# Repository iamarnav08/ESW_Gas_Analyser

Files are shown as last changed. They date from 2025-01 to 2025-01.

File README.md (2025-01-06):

# ESW-Beyond_Infinity
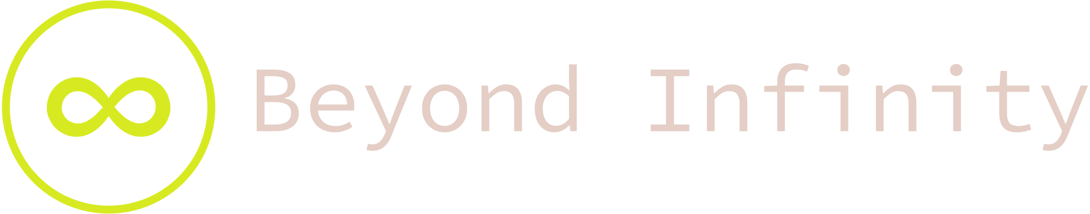
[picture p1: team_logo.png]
team_logo

ESW Project

## Working of MQ 2 sensor

Gases - LPG , CO , smoke

Concentration -> 30 - 500 ppm

Donor atoms (or oxygen vacancies) provide free electrons that can conduct electricity in the tin dioxide.
When the sensor is exposed to air, oxygen gets adsorbed on the surface and traps these donor electrons, reducing conductivity (increasing resistance).
When reducing gases (like methane or CO) are present, they react with the adsorbed oxygen, freeing the donor electrons and increasing the conductivity (lowering resistance).
The sensor measures these changes in resistance (conductivity), and the output voltage increases with the gas concentration because more electrons are available to flow as current.

## Working of MQ7 sensor

The MQ-7 sensor is designed to detect carbon monoxide (CO) using a tin dioxide (SnO₂) sensing element. It works by changing its electrical resistance when CO is present. In clean air, the sensor has high resistance, but when CO interacts with the SnO₂ surface, the resistance decreases.

A key feature of the MQ-7 is its cyclic heating process:

At high temperature (320°C), the sensor cleans itself by adsorbing oxygen molecules.
At low temperature (100°C), the sensor becomes sensitive to CO, reducing its resistance in the presence of CO.
The sensor outputs an analog signal proportional to the CO concentration, making it ideal for CO detectors due to its improved accuracy and selectivity.

## Specialized for CO Detection

MQ-7 is specifically designed to detect carbon monoxide (CO) with high sensitivity. It is fine-tuned through its cyclic heating process, which improves its selectivity for CO and helps reduce interference from other gases. The MQ-7 sensor employs a cyclic heating process, alternating between a high temperature (for cleaning) and a low temperature (for CO detection). This process makes the MQ-7 more selective to CO, reducing false positives from other gases like hydrogen or methane.
The MQ-7 sensor operates on a cyclic heating mechanism with two distinct temperature phases:

High-temperature phase (around 300°C to 350°C): During this phase, the sensor burns off impurities or other gases that may have adsorbed on the surface, ensuring that it is primed for CO detection.
Low-temperature phase (around 100°C to 150°C): This lower temperature is where CO is effectively detected. At this temperature, the CO molecules are adsorbed onto the SnO₂ surface, triggering the redox reaction and thus leading to a measurable change in resistance.

This temperature cycling is essential because it optimizes the sensor's selectivity for CO while minimizing interference from other gases.
Change in Electrical Resistance

## Change in electrical Resistance

As CO is oxidized on the SnO₂ surface, oxygen molecules that were previously adsorbed on the surface as O⁻ ions are released, leading to a reduction in the number of charge carriers trapped on the surface.
This release of oxygen increases the availability of free electrons in the SnO₂ material, leading to a decrease in resistance.
The change in resistance is directly proportional to the concentration of CO in the surrounding air, allowing the sensor to measure CO levels.

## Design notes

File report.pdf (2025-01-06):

# Integrated Gas Analyser

## Course Project for Embedded Systems Workshop EC3.202, Monsoon 2024

Hardik Chadha¹, *, Arnav Sharma², *, Hiten Garg³, *, Kushal Mangla⁴, *, Prof. A. Shrivastava⁵, +
1,2,3,4IIIT Hyderabad,

5CVEST, IIIT Hyderabad
*Team Members,

+Project Advisor

Abstract—Toxic gas exposure in industrial environments, such as manufacturing and chemical processing, poses serious risks to worker safety. Existing gas detection systems are often bulky and lack real-time monitoring, limiting timely responses to hazards; or might be unaffordable for a majority of industrial sites. This project aims to develop a low-cost, portable gas analyzer that enhances safety by providing continuous, real-time detection of harmful gases.

I. INTRODUCTION

Air quality monitoring is becoming increasingly important as environmental pollution, industrial emissions, and household gas leaks pose significant risks to health and safety. Harmful gases like carbon monoxide (CO), smoke, and liquefied petroleum gas (LPG) are major contributors to air pollution and indoor hazards. Real-time monitoring of these gases can help prevent life-threatening incidents by alerting individuals and authorities when the gas concentration reaches dangerous levels.
This paper presents the development of an integrated Gas Analyzer System that detects various harmful gases such as LPG, CO, and smoke using the MQ-2 sensor, and transmits the data wirelessly using LoRaWAN technology. The system is designed to operate in areas with low network coverage and utilizes IoT platforms to provide remote monitoring. This project showcases how embedded systems, sensor technologies, wireless communication, and cloud-based data analysis can be leveraged to create a robust environmental monitoring solution.
The paper details the hardware setup, sensor integration, data transmission via LoRa, cloud data storage using ThingSpeak, CockroachDB and PostgreSQL; and real-time notifications through Twilio, an API service for SMS notifications. We also demonstrate the development of a graphical user interface (GUI) using HTML and CSS to visualize the collected data, making it user-friendly and accessible.

II. PROBLEM STATEMENT

In various industries, toxic gas exposure presents significant health and safety risks to workers. Current solutions often fall short due to their bulkiness, lack of portability and insufficient real-time monitoring, and high costs.
To address these challenges, we aim to develop a low-cost portable gas analyser. The focus will be on making an architecture that can be used to collect and transfer the gas data and is both user-friendly and cost-effective.
The system should be capable of detecting hazardous gases in real-time and transmitting the data wirelessly over long distances. The system must be scalable to monitor multiple locations, offer reliable data visualization, and provide immediate notifications when gas concentrations exceed safety thresholds. Moreover, the solution must work effectively in areas with limited network connectivity, such as rural or industrial zones (mines etc.).
The objective of this project is to design and implement an IoT-based gas monitoring system that integrates gas sensors, long-range wireless communication (LoRaWAN), and cloud-based data storage. The system will offer real-time gas detection, remote monitoring, and automated notifications to ensure timely response to potential hazards, improving overall safety in both industrial and residential environments.

III. OBJECTIVES

Objectives for the project are as follows-
- Real-time Detection of Hazardous Gases: To design a system capable of detecting harmful gases such as LPG, carbon monoxide (CO), and smoke in real-time.
- Long-range Wireless Communication: To implement a reliable, low-power, long-range wireless communication for transmitting gas sensor data over distances of up to few hundred meters.
- Cloud-based Data Storage and Visualization: To enable users to monitor gas concentration levels remotely via a web-based graphical user interface (GUI).
- Automated Threat Notifications: To implement mechanism for sending real-time notifications to users when gas concentrations exceed predefined safety thresholds, ensuring timely response to potential hazards.
- On-site Monitoring: To provide a local monitoring solution using an LCD display that shows current gas levels on-site for immediate assessment.
- Data Redundancy and Offline Access: To ensure data reliability by storing sensor readings locally on an SD card in case of network connectivity loss, allowing periodic retrieval and analysis of historical data.
- User-friendly Web Application: To develop a web-based GUI that allows users to interact with the system, view real-time data, analyze historical gas levels, and configure alerts, making the system accessible and easy to use.
- Scalability for Multiple Locations: To design the system to be scalable and capable of monitoring multiple sites, making it suitable for industrial, residential, and remote environments.

IV. PROPOSED SOLUTION

Our solution comprises of the following components-
- MQ-2 Gas Sensor for Gas Detection: The system uses the MQ-2 gas sensor to detect the concentration of harmful gases such as LPG, CO, and smoke. The MQ-2 sensor provides reasonably accurate measurements of gas concentrations, suitable for most practical applications. This sensor can detect increase in concentrations of gases, allowing early detection of leaks or hazardous conditions while being reasonably cheap.
- ESP-32 Microcontroller as Microcontroller: An ESP-32 microcontroller serves as the central unit for the system. It collects data from the MQ-2 sensor and prepares it for transmission. The ESP-32 is an ideal choice due to its low power consumption, built-in Wi-Fi, and SPI communication capabilities, making it highly suitable for our usecase.
- LoRaWAN for Long-range Wireless Communication: To enable long-distance communication between the gas detection unit and the monitoring center, the system employs Ra-02 LoRaWAN modules. LoRa technology is chosen for its ability to transmit data over distances of up to few hundred meters with minimal power consumption. This ensures that gas levels can be monitored in real-time, even in remote or industrial environments with limited or no internet connectivity. Also, its range can be increased easily by introducing repeater modules.
- Cloud-based Storage and Visualization using ThingSpeak and CockroachDB: The collected gas data is transmitted to the ThingSpeak IoT platform, where it is stored and visualized in real-time. ThingSpeak provides a user-friendly dashboard that displays gas concentration levels in the form of graphs and charts. This allows users to analyze historical data and observe trends in gas levels, which can be critical for detecting recurring patterns or identifying potential hazards. The data from ThingSpeak is retrieved using Node.JS integrated with PostgreSQL. This data is uploaded to a cloud database created on CockroachDB, a distributed Database Management System. This online database can be used to create a user interface platform, enabling multiple users on our platform along with allowing users to view their sensor data securely.
- Real-time Notifications via Twilio API: To enhance safety, the system is integrated with Twilio’s API to send real-time WhatsApp notifications to users when gas concentrations exceed predefined safety thresholds. This feature ensures immediate alerts are sent to responsible parties, enabling prompt action to prevent potential health and safety risks.
- Local Monitoring via LCD Display: In addition to remote monitoring, the system includes an on-site LCD display to show real-time gas concentration levels. This allows personnel near the gas detection unit to quickly assess the situation and take necessary actions without needing to access the web-based interface.
- SD Card for Local Data Storage: To ensure data reliability, especially in areas with intermittent network connectivity, the system includes an SD card module for local storage of sensor readings. This provides data redundancy and allows for the retrieval and analysis of historical data in case of network or cloud service failures.
- User-friendly Web Application for Remote Monitoring: User-friendly Web Application for Remote Monitoring: Our motive is to create a application that allows users to remotely monitor the system from any internetconnected device. So that it provides an intuitive platform to track real-time gas levels, set customizable alert thresholds, and access historical data. Creating a system which is both accessible and effective for monitoring and alert configuration.
V. SYSTEM ARCHITECTURE

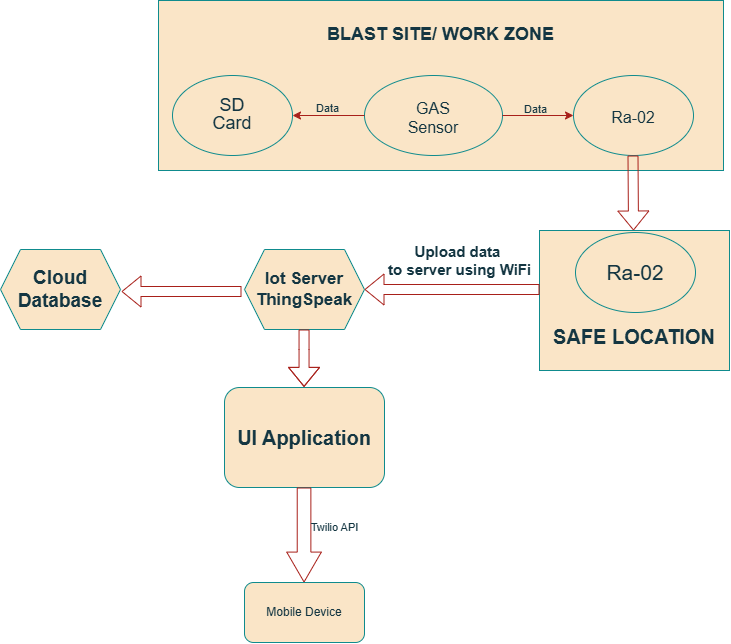
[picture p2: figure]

Fig. 1: System Architecture Diagram

The system architecture consists of multiple hardware and software components working together to ensure seamless data acquisition, transmission, processing, and visualization.

A. Hardware Components

The hardware setup includes sensors, a microcontroller, and communication modules:

- ESP-32 Microcontroller: In this setup, two ESP32 modules are used: one as the main node (sender module) paired with sensor, SD card and LCD, and the other as the receiver for the LoRa mechanism. The code for these is present here: Receiver [1] and Sender [1].
- MQ-2 Gas Sensor: One MQ-2 sensor is used for gas detection in our implementation, though the architecture allows the sensor change to more advanced and precise sensors with minimal changes in the code.
- LoRaWAN (Ra-02) Module: Two Ra-02 LoRa modules are used for transmitting data over long distances using low-power, long-range wireless communication. One module is at the sender node to transmit sensor data to a receiver node where the other module is located.

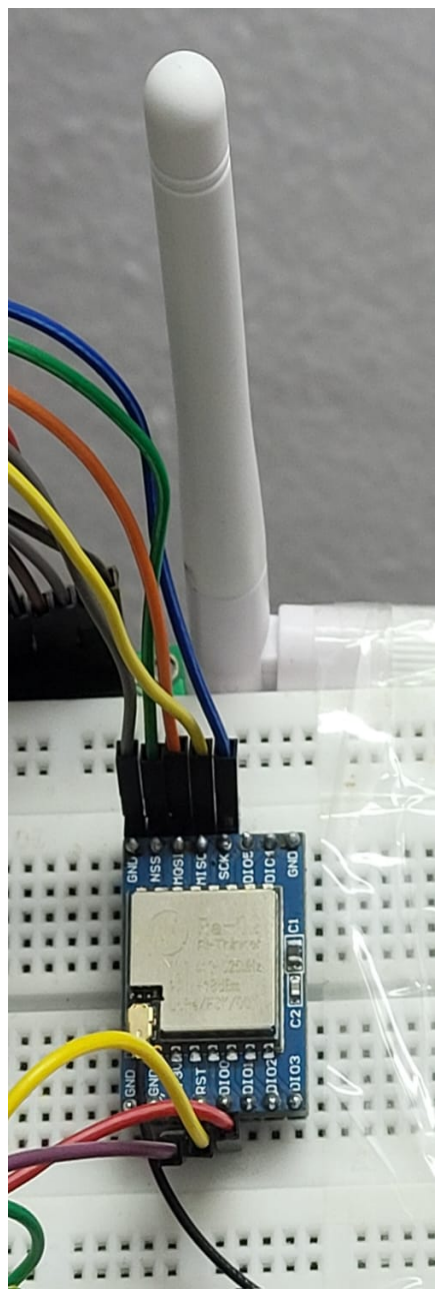
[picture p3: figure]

Fig. 2: LoRa Module

- LCD Display: A small LCD display is attached to the system to provide real-time, on-site monitoring. The display shows current gas concentrations, and displays whether the conditions are safe or not.

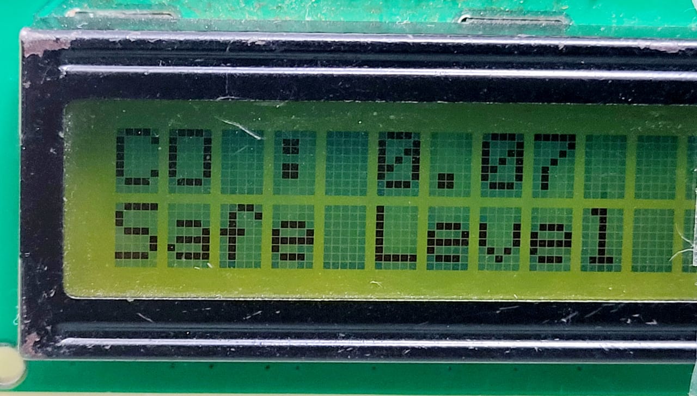
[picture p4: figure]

Fig. 3: LCD Display

- SD Card Module and SD Card: To ensure data persistence, the system is equipped with an SD card module [5], which helps writing the data to the SD card. Also a 32 GB SD card formatted in Fat32 file system is used to store the data. The SPI [4] pins of the ESP32 are used for communicating with the SD card module.

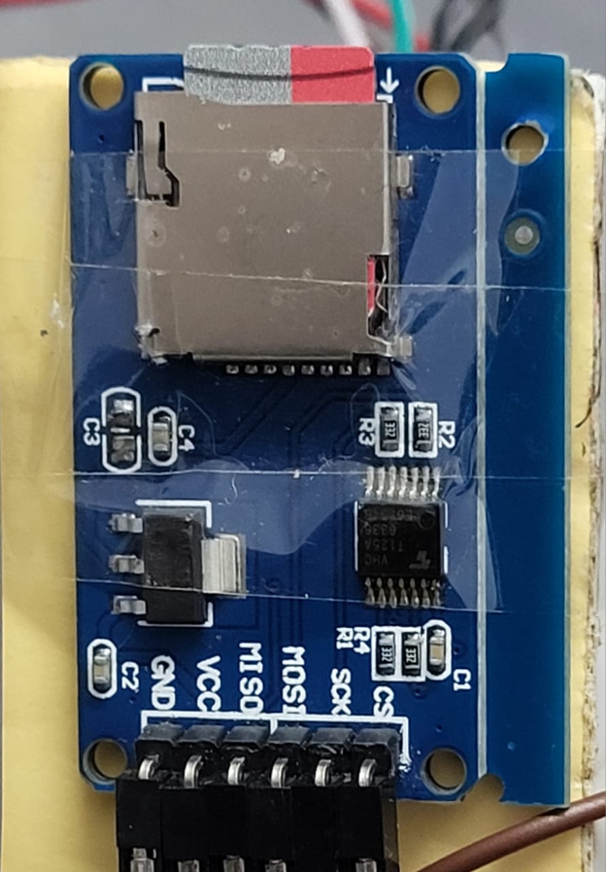
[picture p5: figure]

Fig. 4: SD Module

B. Cloud and Data Management

The system leverages cloud services for real-time data visualization, storage, and alerts:

- CockroachDB: An SQL database is integrated into the system with the help of CockroachDB, providing a distributed, scalable and resilient database solution for storing data required in our solution. The handling of concurrent requests, and upholding of ACID 1 characteristics for the database make CockroachDB ideal for use in an IoT application such as ours [7]. Initial schema of the database used is shown in the image below. The database can be scaled as per the needs of the customer.

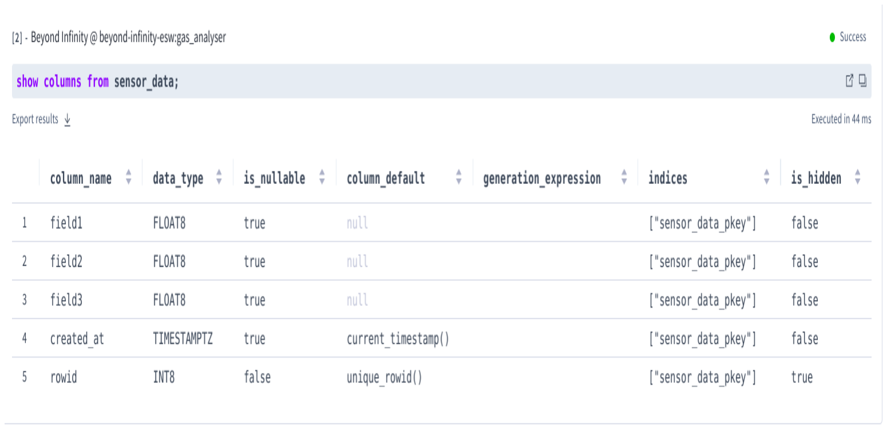
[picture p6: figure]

Fig. 5: DB Schema used

- ThingSpeak IoT Platform [3]: After data is transmitted to the receiver node, it is uploaded to ThingSpeak. It provides a comprehensive environment for real-time data collection and visualization. Data is presented as timeseries graphs, allowing users to track gas concentration trends over time. It has built-in analysis tools help in identifying patterns.
- Twilio API Integration: The system is integrated with Twilio to send real-time WhatsApp alerts to users when gas concentrations exceed safety thresholds. This feature ensures immediate notification in case of dangerous gas levels, enhancing the overall safety of the system.

1Atomicity, Consistency, Isolation and Durability properties ensure reliability of a database in transactions.

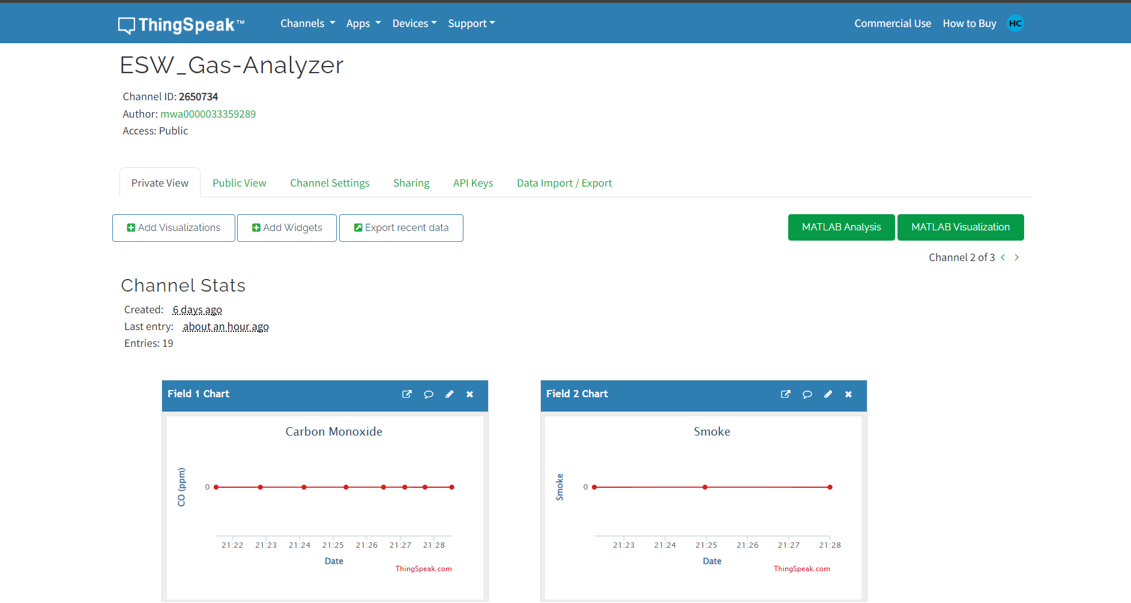
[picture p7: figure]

Fig. 6: Thingspeak Server

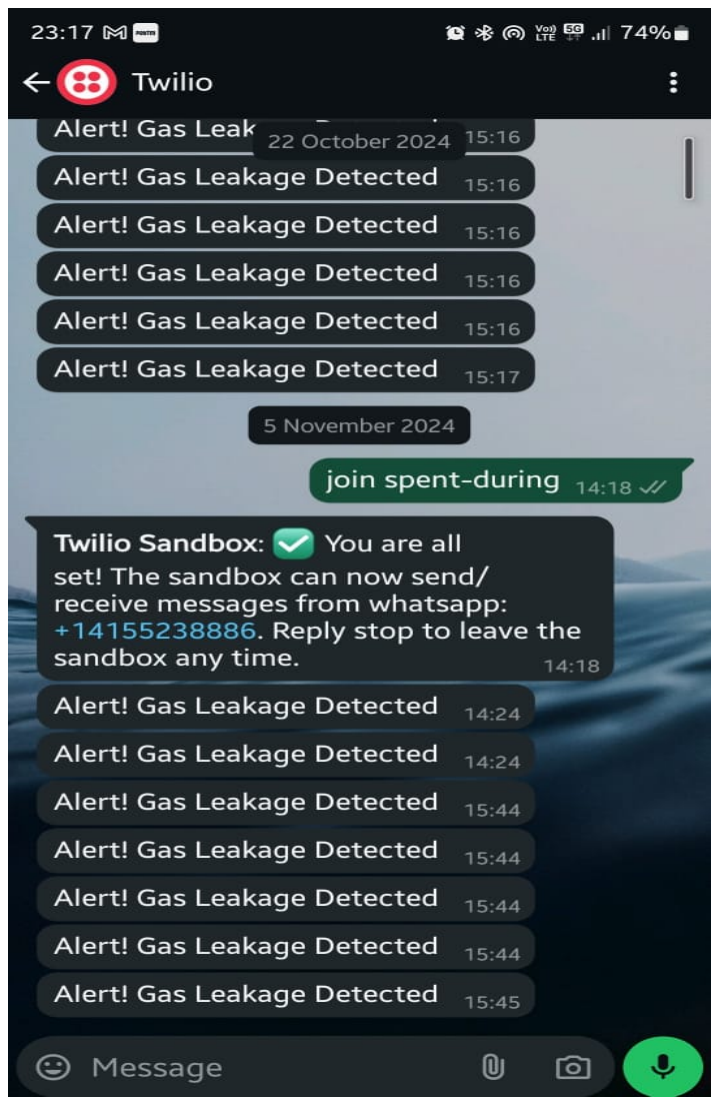
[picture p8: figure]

Fig. 7: Twilio API

C. User Interface

A web-based GUI is developed to provide users with a comprehensive view of the system’s operation:

- Web Application [6]: A web-based graphical user interface (GUI) was developed using Node.js, Express.js, HTML, and CSS, offering a user-friendly interface for accessing sensor data remotely. Users can view real-time gas concentration levels and access historical data. It stores the gas data in one database and the registered users in another database.The employees of the company can register and login to view the real time data of the sites where the model is deployed.

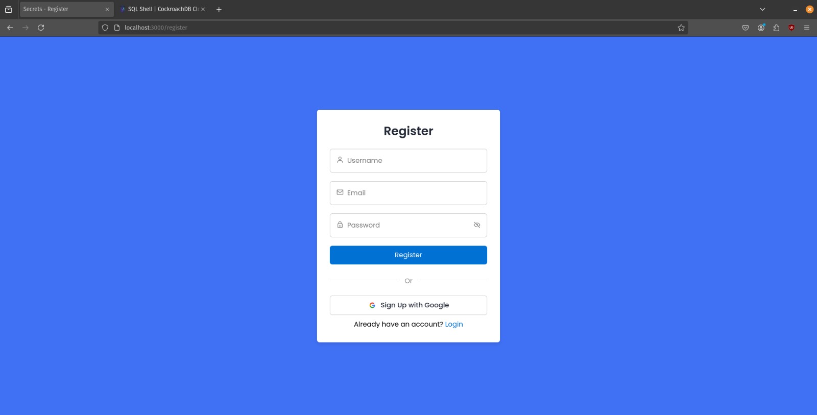
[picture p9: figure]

Fig. 8: Website Register Page

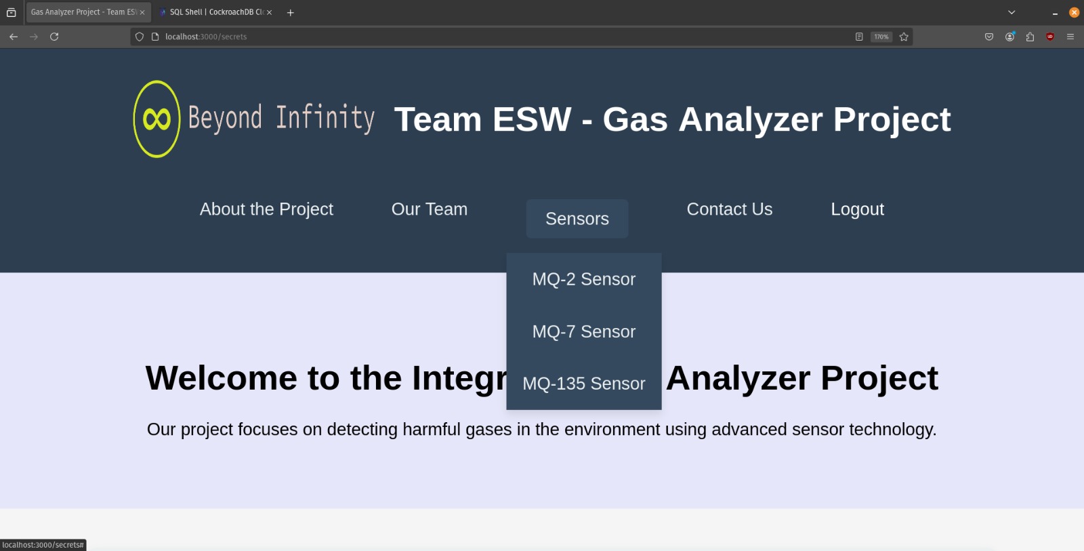
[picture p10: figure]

Fig. 9: Website Home Page

VI. PCB DESIGN

We designed and fabricated Printed Circuit Boards for the sender and receiver modules of our solution using Autodesk Eagle.

A. Sender Module

The images for the sender module’s circuit diagrams and board diagrams can be seen below. The files can be accessed through the GitHub repository. [8]

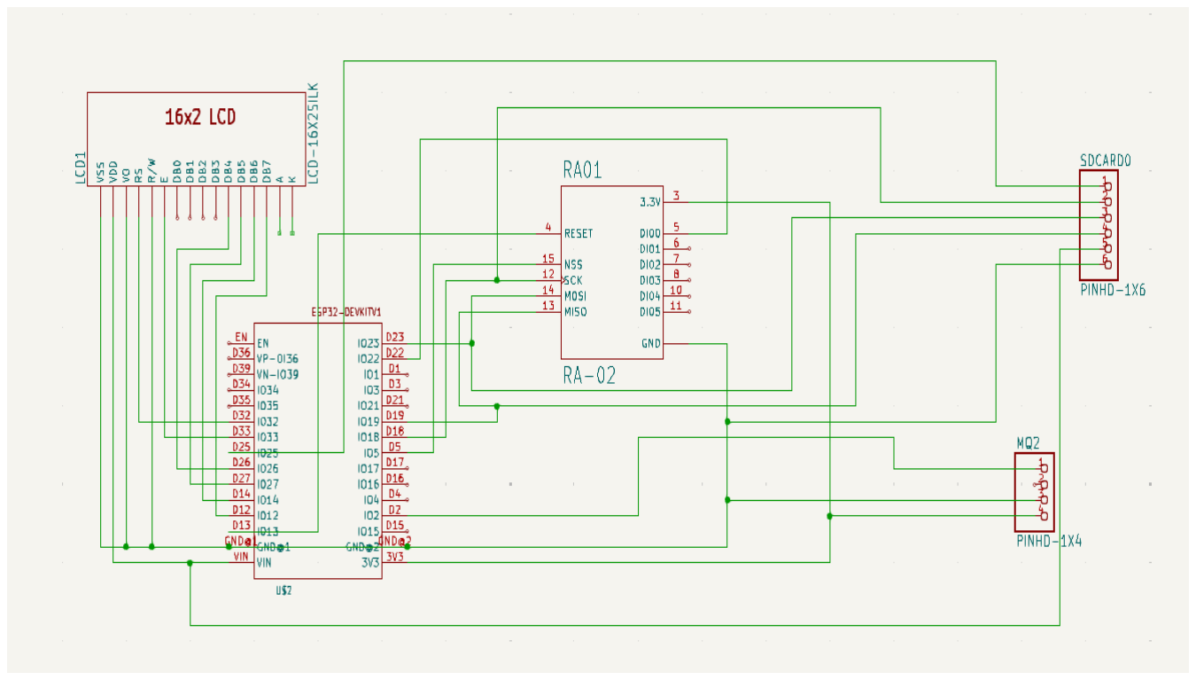
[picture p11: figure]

Fig. 10: Sender Circuit Diagram

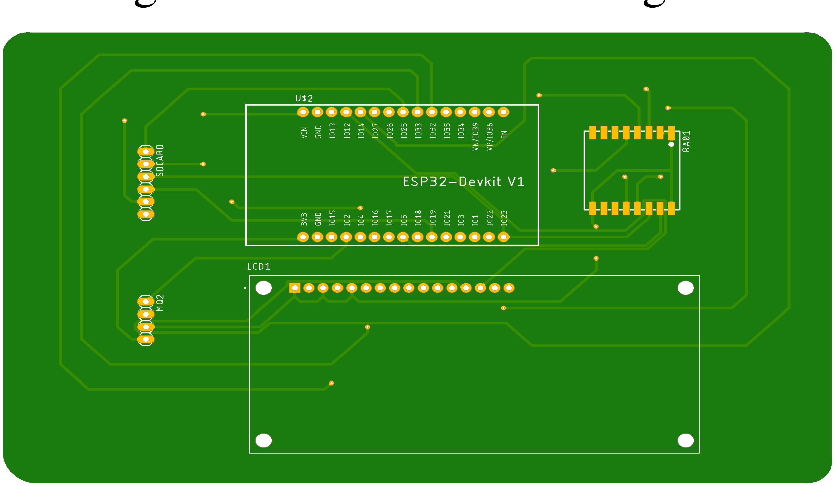
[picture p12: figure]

Fig. 11: Sender Board(Top View)

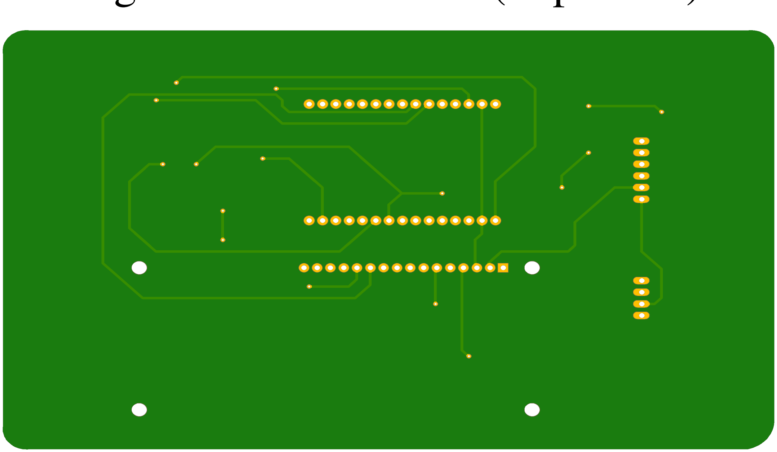
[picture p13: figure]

Fig. 12: Sender Board(Bottom View)

B. Receiver Module

The images for the receiver module’s circuit diagram and board diagrams can be seen below. The files can be accessed through the GitHub repository. [8]

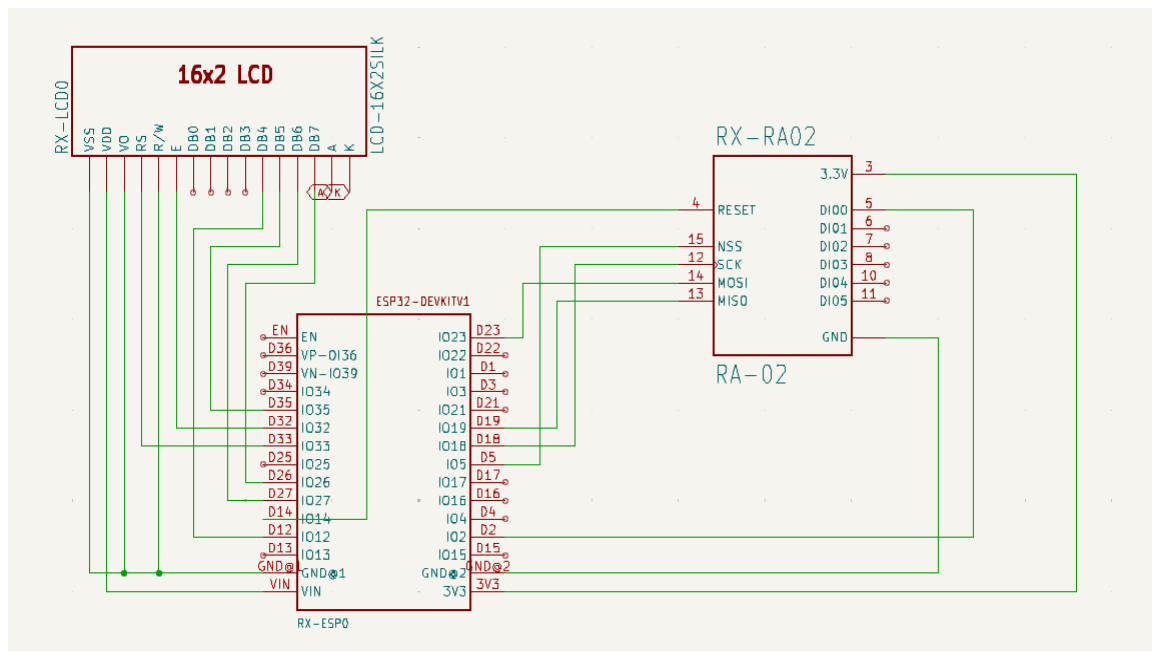
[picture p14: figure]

Fig. 13: Sender Circuit Diagram

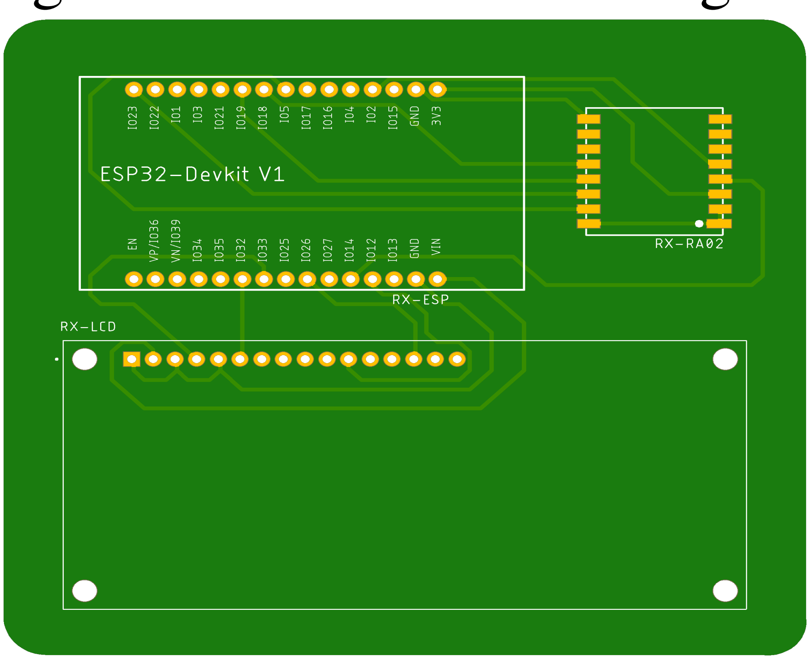
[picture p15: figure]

Fig. 14: Receiver Board(Top View)

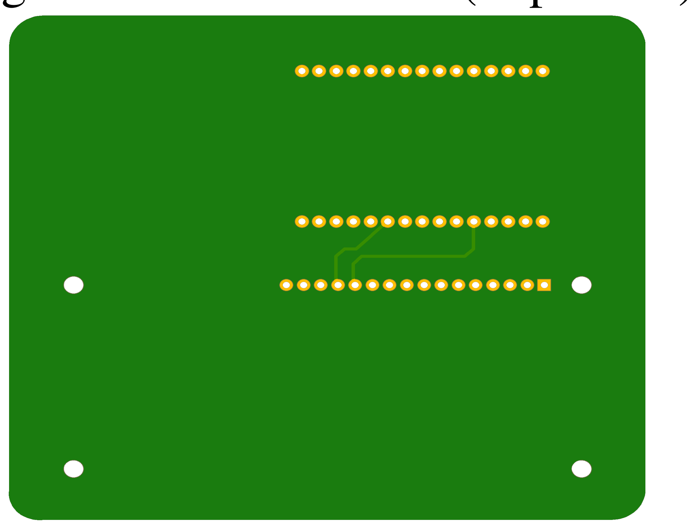
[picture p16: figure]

Fig. 15: Receiver Board(Bottom View)

VII. 3D DESIGN

We designed the 3D design for the sender and receiver modules of our solution using Fusion 360. The link to all files can be found here : [9]

A. Sender Module

The images for the sender 3D design can be seen below. The files can be accessed via the GitHub repository.

B. Receiver Module

The images for the receiver 3D design can be seen below. The files can be accessed through the GitHub repository.

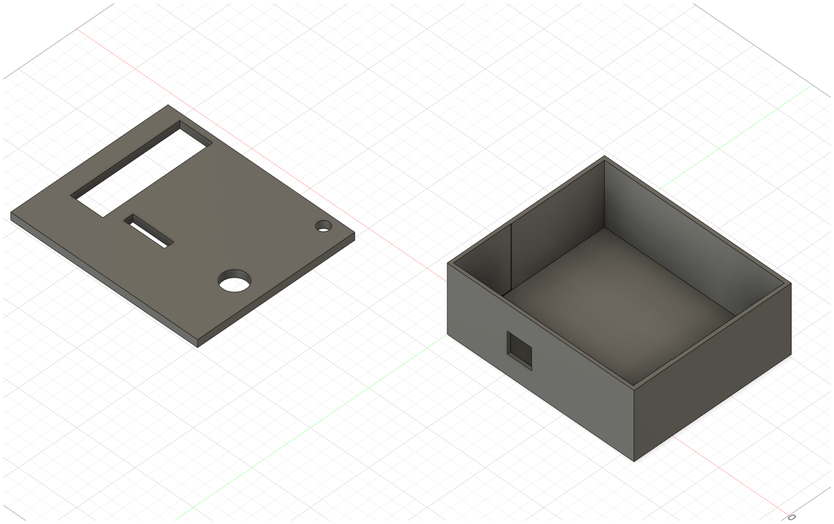
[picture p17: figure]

Fig. 16: Sender Module

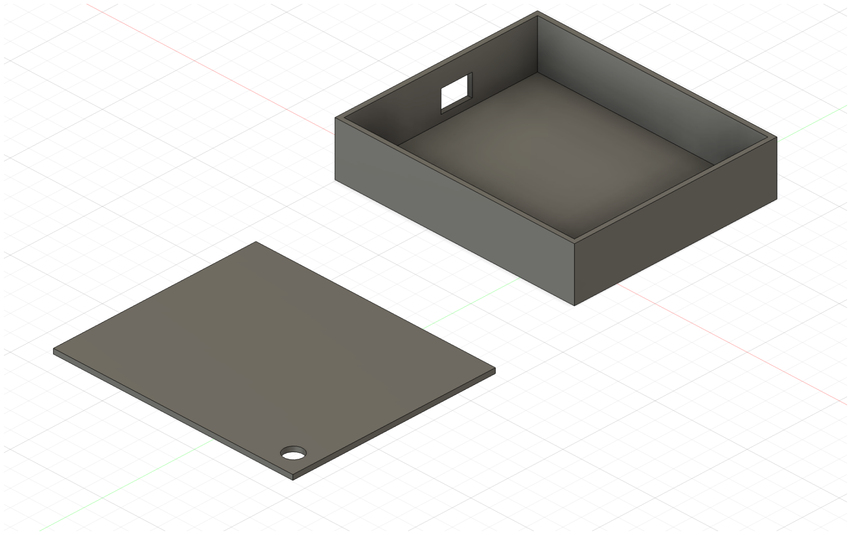
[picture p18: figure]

Fig. 17: Receiver Module

VIII. LORA ANALYSIS

To evaluate the performance and reliability of the Lo-RaWAN communication system, we conducted a some experiments over varying distances. The purpose of these tests was to measure the strength of the LoRa signal(RSSI), assess packet transmission quality(SNR), and analyze the effect of obstacles (such as walls and floors) on signal integrity.

A. Testing LoRa Values Over a Distance of 1-5 Meters

In this experiment, we tested the LoRa signal strength and packet transmission performance over a short distance of 1-5 meters in an open area. The purpose was to establish baseline performance in an ideal, interference-free environment.

- Setup: The LoRa transmitter was placed at one end of the room, and the receiver was moved to distances ranging from 1 meter to 5 meters.
- Parameters measured: Signal-to-Noise Ratio (SNR), Received Signal Strength Indicator (RSSI), and packet delivery success.
- Results: The signal strength was optimal, with RSSI values remaining between -30 dBm and -40 dBm. Packet transmission success was near 100%, with minimal packet loss and high SNR values ranging from 8 to 10 dB.

B. Same Floor Experiment (5-30 Meters)

We then extended the test distance to 5-30 meters on the same floor. This experiment was designed to assess LoRa’s performance in a confined indoor environment with potential interference from furniture and walls.

- Setup: Both the transmitter and receiver were placed on the same floor, with the distance increased gradually to 30 meters. Obstacles like furniture were present in the room.
- Parameters measured: RSSI, SNR, and packet success rate.
- Results: RSSI values dropped slightly, ranging from -45 dBm to -60 dBm as the distance increased. The SNR decreased down to -2dB on average due to rooms in between and also the increasing distance, and packet loss began to occur, especially at the 30-meter mark.
C. Different Floor Experiment (1-2 Floors)

In this test, we analysed LoRa performance between different floors of the same building. This experiment introduced structural interference, such as concrete ceilings and walls, which are common in multistory buildings.

- Setup: The transmitter was placed on the third floor, while the receiver was taken to the first, second, and fourth floors.
- Parameters measured: RSSI, SNR, and packet success rate.
- Results: The signal degraded more significantly, with RSSI values dropping to -70 dBm on the first floor and -80 dBm on the second floor. The SNR values observed a very pattern-like behaviour that is, when the distance was increased until the stairs then the SNR value decreased and when the receiver was just a floor below then it increased due to less obstacles between them. This change in value was observed for each descending floor. Packet loss increased significantly in this case.
D. Long Distance

For the final experiment, we tested LoRa communication between two different buildings to evaluate signal penetration through obstacles like trees, people and across open spaces between the buildings.

- Setup: The transmitter was placed in one building, while the receiver was taken to an adjacent building separated by a distance of approximately 30-75 meters.
- Parameters measured: RSSI, SNR, and packet success rate.
- Results: The RSSI values dropped significantly, falling to -90 dBm at 30 meters and -100 dBm at 30 meters. The SNR dropped significantly from 5 to -8 dB, and the packet success rates fell. The signal strength reduced significantly with the distance increased.
E. Analysis Summary
The experiments demonstrate that LoRa performs exceptionally well in short-range, open environments with minimal interference. However, as obstacles such as walls, floors, and the distance between buildings increase, signal strength and reliability diminish significantly. While LoRa is effective for long-range communication in rural and less obstructed areas, its performance in dense urban environments or multi-story buildings may require the use of repeaters or stronger signal antennas to ensure reliable communication.

IX. COST ANALYSIS

The cost analysis of the Gas Analyzer project is divided into hardware costs and software/infrastructure costs. All values are provided in approximate INR.

A. Hardware Costs
The hardware components include sensors, microcontrollers, communication modules, and other peripherals. Below is an estimated breakdown of the costs in INR:
Component | Quantity | Unit Cost (INR) | Total Cost (INR)
ESP-32 Module | 2 | 500 | 1,000
MQ-2 Gas Sensor | 1 | 150 | 150
Ra-02 LoRa Module | 2 | 500 | 1,000
SD Card Module | 1 | 100 | 100
16 GB SD Card | 1 | 400 | 400
LCD Display | 1 | 200 | 200
Other Connectors | - | 100 | 100

TABLE I: Hardware Costs in INR

Total Hardware Cost (Approx.): Rs. 3,000

B. PCB Cost
The cost of fabrication of the custom PCB that we have created for the Sender and Receiver.
PCB Fabrication Cost: Rs. 3,500
C. Software/Infrastructure Costs
When the system is deployed in a real-world scenario, there will be associated software and infrastructure costs. These may include expenses for cloud services, IoT platform subscriptions, data storage, and maintenance of the software components necessary for seamless operation.
D. Total Estimated Project Cost
The total estimated cost of the Gas Analyzer project, including hardware and PCB costs only, is provided below: Total Project Cost (Approx.): Rs. 6,500
X. MODULAR HARDWARE DESIGN

One of the key strengths of our Gas Analyzer project is the modular design of the hardware. The system is structured in such a way that the MQ-2 sensor, which is primarily used for detecting LPG, smoke, and carbon monoxide, can be easily replaced with other gas sensors with minimal modifications to the code.

A. Flexible Sensor Integration

The hardware architecture supports a variety of gas sensors due to the uniform pin configurations and standard interfacing techniques employed. This design allows for seamless integration of sensors such as MQ-7 annd MQ-135 without the need for significant hardware modifications.

B. Minimal Code Changes

The flexibility in the design is complemented by the software, where only minor adjustments to the sensor calibration parameters and data reading logic are required when switching sensors. This modular approach reduces the complexity of reconfiguring the system for different gases, making it highly adaptable to various environmental monitoring needs.
For instance, replacing the MQ-2 sensor with a new sensor involves:
- Updating the sensor input methods in the Sender Module code according to the new sensor library.
- Adjusting the gas concentration thresholds specific to gases the new sensor measures.
- If the new gases are not already in the system, tables related to their data needs to be changed in the system. This approach ensures that the system can be repurposed for a wide range of applications with minimal effort, increasing its utility in both industrial and residential settings.
C. Future Expansion
This project demonstrates a functional implementation of an IoT system using ESP32 modules with LoRa communication. However, there are several areas for potential improvement and future enhancements:
1) Sensor Calibration: Adding algorithms for better sensor calibration than the library available calibration mechanism to enhance system accuracy in detecting the gas concentrations.
2) Usage of Better Sensors: Explore the integration of higher-precision or industrial-grade sensors to improve the accuracy and reliability of the data collected, ensuring better performance in critical applications, though this will come at cost of increasing the price of the device.
3) Interfacing with Additional Sensors: Extend the system to interface with other types of sensors, such as environmental sensors (temperature, humidity) or industrial sensors (vibration, pressure) for diversified applications.
4) Power Optimization: Investigate techniques to optimize power consumption in the ESP32 modules without compromising real-time data transmission. Solutions could include efficient scheduling of operations or the use of low-power components where feasible.
5) Integration with Advanced IoT Platforms: Extend the system by integrating it with advanced IoT platforms like AWS IoT Core, Microsoft Azure, or Google Cloud IoT for enhanced data processing, analytics, and visualization.
6) Multi-Node LoRa Network: Expand the system to support multiple sender nodes communicating with a single receiver, enabling the development of a larger sensor network for broader applications.

XI. SUMMARY

The Integrated Gas Analyzer is an IoT-based solution designed for real-time monitoring of harmful gases such as LPG, carbon monoxide (CO), and smoke. Utilizing an ESP-32 microcontroller and the MQ-2 sensor, the system collects gas concentration data and transmits it using LoRaWAN modules for long-range, low-power communication. The data is visualized on a web-based GUI and stored on cloud platforms like ThingSpeak and CockroachDB, ensuring remote access and historical analysis. Additionally, the system incorporates Twilio API for real-time WhatsApp notifications and an LCD display for on-site monitoring. Experiments demonstrated LoRa’s effective performance in short-range environments but noted signal degradation over longer distances and through obstacles. The project’s modular design allows for easy sensor replacement with minimal code changes, making it scalable and adaptable to various applications. With a total cost of approximately Rs. 6,500, the system combines affordability, reliability, and user-friendliness, offering a practical solution for industrial and residential safety monitoring.

XII. PERSONAL CONTRIBUTIONS

- Hardik Chadha (2023111031):
1) Integrated the SD card module with the Sender module.
2) Integrated the LCD display with the Sender Module.
3) Wrote the code for integrating SD card and LoRa module on the same SPI pins of the sender module ESP and debugging the issues faced in these parts.
4) Helped in the inititial testing of MQ-2 Sensor.
5) Helped in the testing of LoRa Modules.
6) Helped in the data collection for different experiments for LoRa.
7) Assisted in the Soldering of the PCB connections.
- Arnav Sharma (2023111033):
1) Integrated HTML with ThingSpeak, to enable live retrieval of data from ThingSpeak to be displayed on the web-page.
2) Used NodeJS and PostgreSQL to connect server, ThingSpeak and CockroachDB.
3) Created database/backend on CockroachDB Cloud for storing data.
4) Made the circuit schematic to be used in the PCB Design.
5) Designed the PCB using Autodesk Eagle.
6) Helped in collection of data for LoRa analysis.
7) Made the PPT’s for progress of each week, as well as for the final presentation.
- Kushal Mangla (2023101026):
1) Wrote the codes for Lora Modules.

2) Coding and implementation of TWILIO API with Node and Express JS.
3) Made the backend for the the user interface of our website, implementing nodejs, expressjs, postgress.
4) Intergrating the EJS files with our backend server.
5) Helped in hardware integration with Hiten.
6) Helped in data collection for the lora analysis.
7) Analysed the data using python scripts and made graphs.
8) Made the 3D design for both the sender and receiver modules.
- Hiten Garg (2023101116):
1) Analyzed the codes along with Kushal.
2) Implementation | of | messaging | system | using
TWILIO API with whatsapp integration.
3) Made the HTML page for the website to showcase the overview of our project.
4) Implemented the hardware like connections for both the sender and receiver modules.
5) Worked on data collection for different experiments.
6) Analysed the data using python scripts and made graphs.
7) Made the 3D design for both the sender and receiver modules.

REFERENCES

[1] Lora Reciever (https://github.com/Kushal-Mangla/ESW-Project/tree/main/ESP%20Codes/Reciever)
[2] Lora Sender (https://github.com/Kushal-Mangla/ESW-Project/blob/main/ESP%20Codes/Sender/Sender.ino)
[3] Thingspeak Channel (https://thingspeak.mathworks.com/channels/2687973/private_show)
[4] Resource for SPI (https://www.analog.com/en/resources/analog-dialogue/articles/introduction-to-spi-interface.html)
[5] SD Card adapter Interfacing (https://www.electronicwings.com/esp32/microsd-card-interfacing-with-esp32)
[6] Complete GUI Code (https://github.com/Kushal-Mangla/ESW-Project)
[7] CockroachDB Features (https://www.cockroachlabs.com/docs/stable/architecture/transaction-layer)
[8] PCB Files (https://github.com/Kushal-Mangla/ESW-Project/tree/main/PCB%20Files)
[9] 3D Designs (https://github.com/Kushal-Mangla/ESW-Project/tree/main/3D%20Designs)

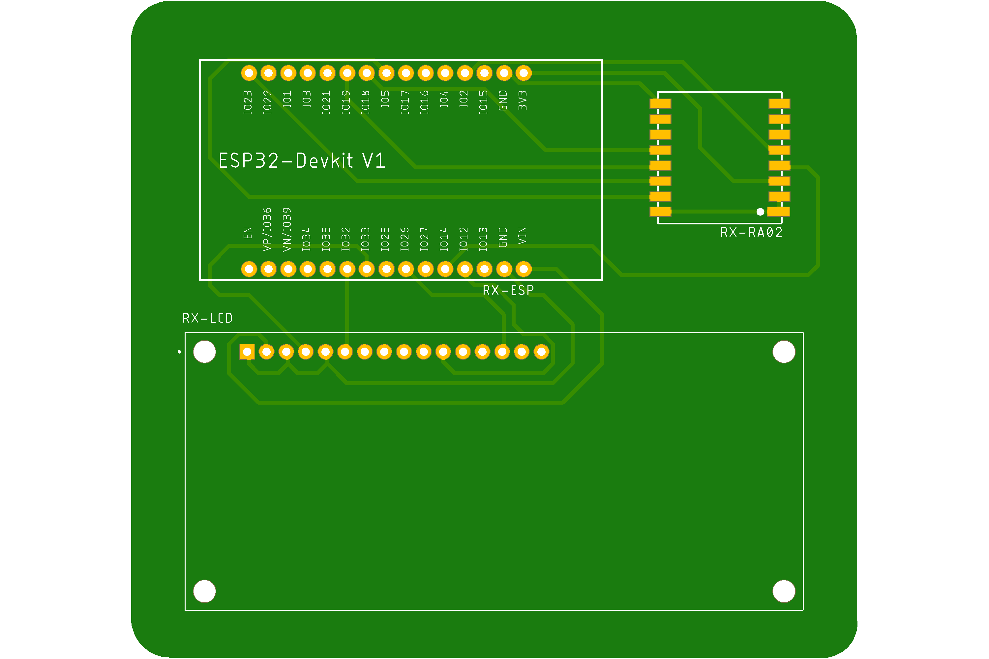
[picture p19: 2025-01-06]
PCB Files/receiver_top.png

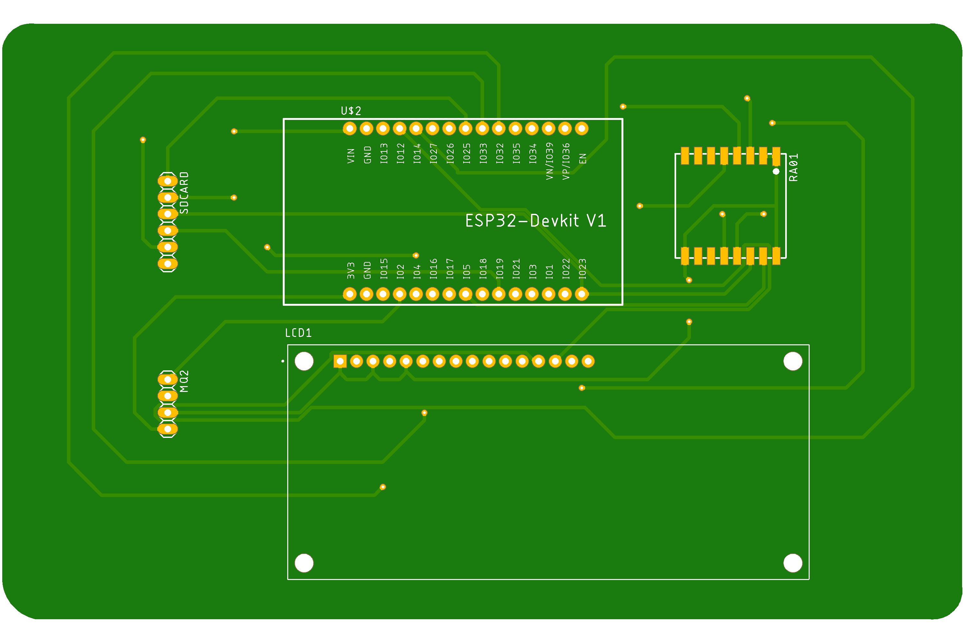
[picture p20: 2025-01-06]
PCB Files/sender_top.png

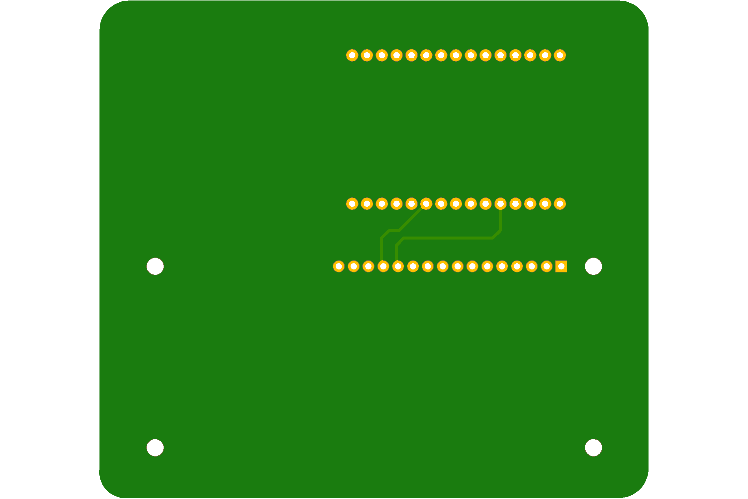
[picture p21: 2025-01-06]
PCB Files/receiver_bottom.png

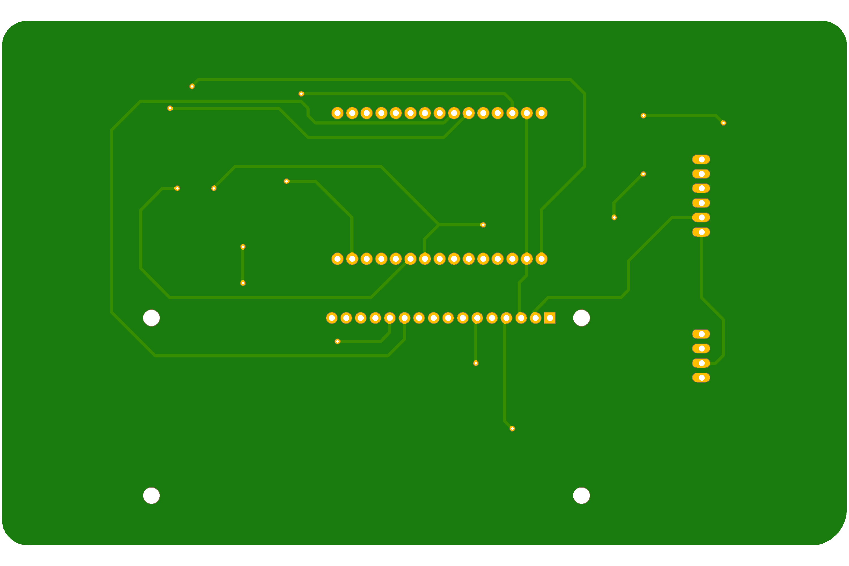
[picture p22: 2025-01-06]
PCB Files/sender_bottom.png

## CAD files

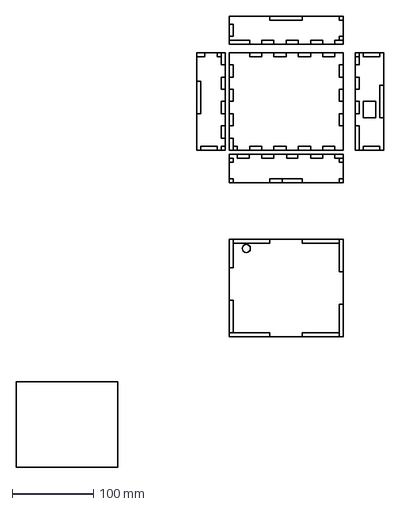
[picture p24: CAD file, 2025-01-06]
3D Designs/Receiver with grooves.dxf
451.8 x 554.4 mm

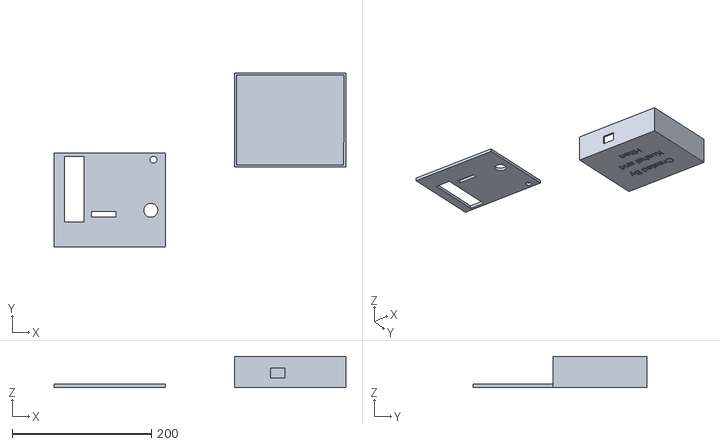
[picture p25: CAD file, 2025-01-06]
3D Designs/Sender.stl
418.9 x 249.6 x 45.1

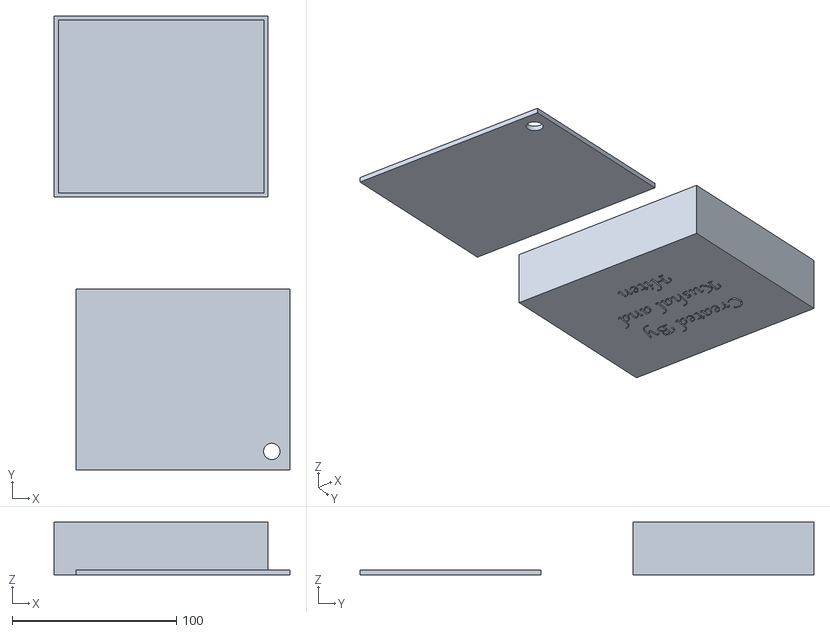
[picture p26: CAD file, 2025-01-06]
3D Designs/Receiver.stl
143.4 x 276.2 x 32.0

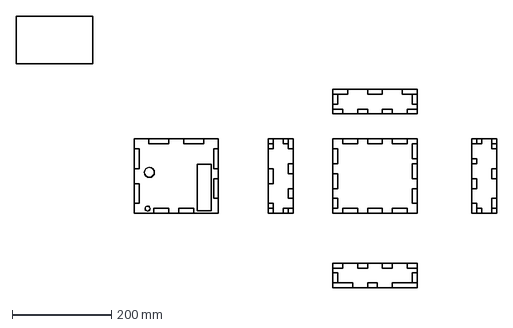
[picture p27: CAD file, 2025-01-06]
3D Designs/Sender with grooves.dxf
967.0 x 547.0 mm

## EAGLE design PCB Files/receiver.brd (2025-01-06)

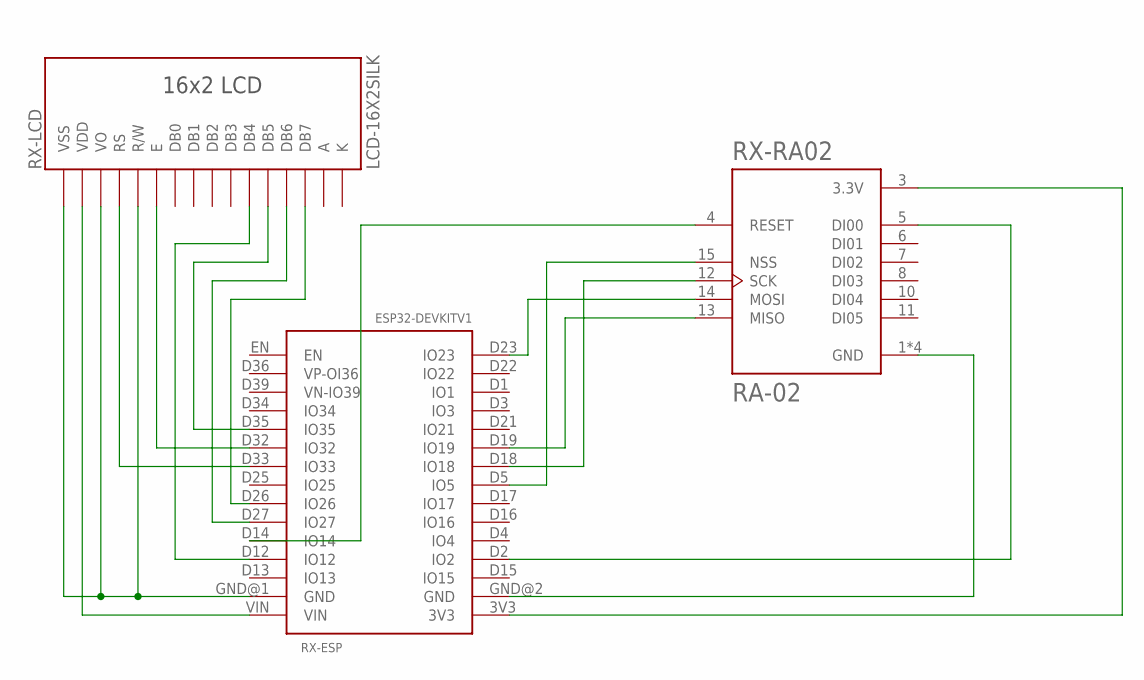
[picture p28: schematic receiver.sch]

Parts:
RX-ESP: ESP32DEVKITV1; ESP32-DEVKITV1
RX-LCD: LCD-16X2SILK; MODULE_LCD-16X2
RX-RA02: RA-02

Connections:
A: RX-LCD.15 (A)
K: RX-LCD.16 (K)
unnamed: RX-ESP.D23 (IO23), RX-RA02.14 (MOSI)
unnamed: RX-ESP.D2 (IO2), RX-RA02.5 (DI00)
unnamed: RX-ESP.GND@2 (GND), RX-RA02.1 (GND), RX-RA02.2 (GND), RX-RA02.9 (GND), RX-RA02.16 (GND)
unnamed: RX-ESP.D19 (IO19), RX-RA02.13 (MISO)
unnamed: RX-ESP.D18 (IO18), RX-RA02.12 (SCK)
unnamed: RX-ESP.D5 (IO5), RX-RA02.15 (NSS)
unnamed: RX-ESP.D14 (IO14), RX-RA02.4 (RESET)
unnamed: RX-ESP.3V3, RX-RA02.3 (3.3V)
unnamed: RX-ESP.VIN, RX-LCD.2 (VDD)
unnamed: RX-ESP.D32 (IO32), RX-LCD.6 (E)
unnamed: RX-ESP.D33 (IO33), RX-LCD.4 (RS)
unnamed: RX-ESP.D27 (IO27), RX-LCD.13 (DB6)
unnamed: RX-ESP.D35 (IO35), RX-LCD.12 (DB5)
unnamed: RX-ESP.D12 (IO12), RX-LCD.11 (DB4)
RX-N$1: RX-ESP.D26 (IO26), RX-LCD.14 (DB7)
RX-N$4: RX-ESP.GND@1 (GND), RX-LCD.1 (VSS), RX-LCD.3 (VO), RX-LCD.5 (R/W)

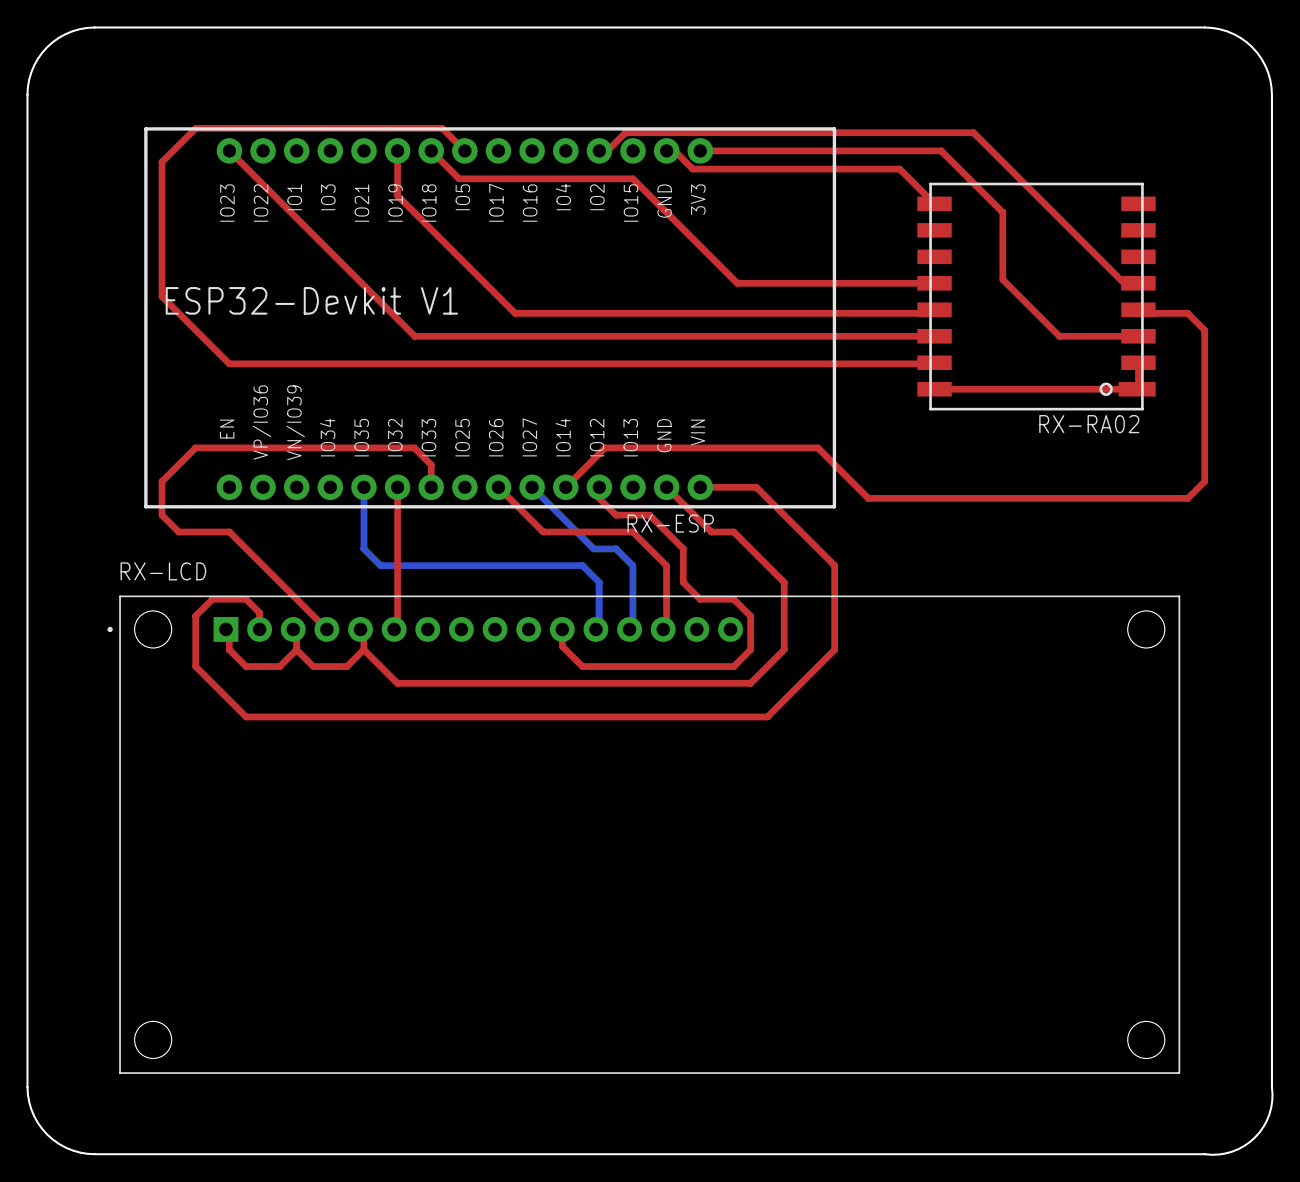
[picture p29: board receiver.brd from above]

Board: 2 copper layers, 94.0 x 85.1 mm, 3 parts (0 on the bottom side), 16 nets.

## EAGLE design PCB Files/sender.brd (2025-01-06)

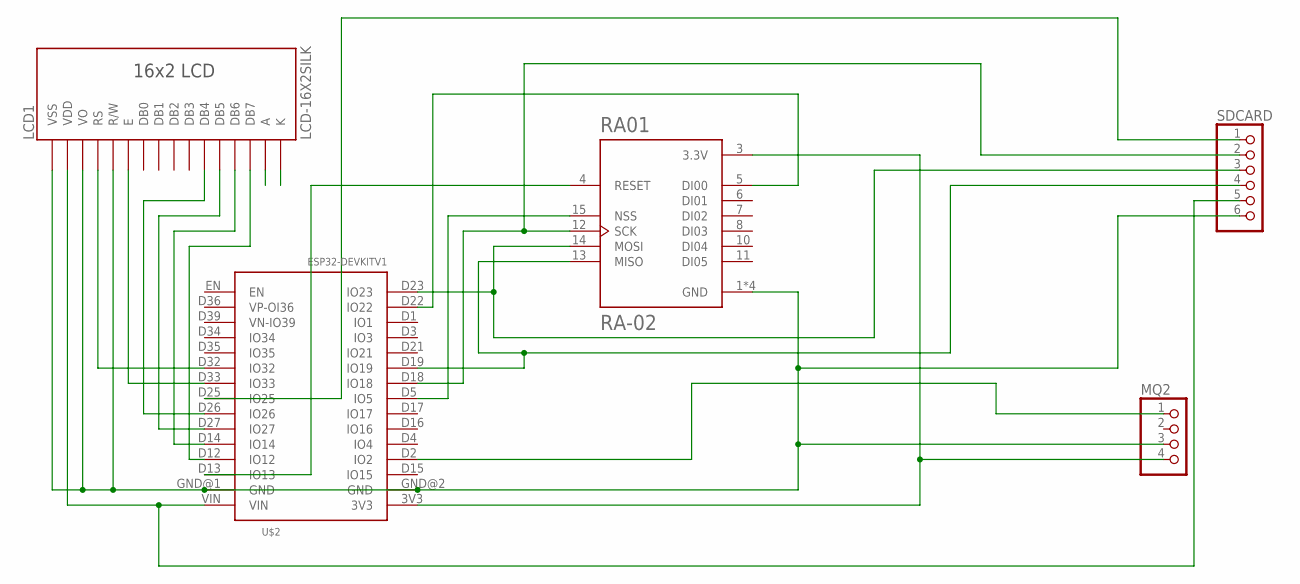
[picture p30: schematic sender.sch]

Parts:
LCD1: LCD-16X2SILK; MODULE_LCD-16X2
MQ2: PINHD-1X4; 1X04
RA01: RA-02
SDCARD: PINHD-1X6; 1X06
U$2: ESP32DEVKITV1; ESP32-DEVKITV1

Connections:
unnamed: RA01.4 (RESET), U$2.D13 (IO13)
unnamed: RA01.12 (SCK), SDCARD.2, U$2.D18 (IO18)
unnamed: RA01.15 (NSS), U$2.D5 (IO5)
unnamed: RA01.5 (DI00), U$2.D22 (IO22)
unnamed: RA01.13 (MISO), SDCARD.4, U$2.D19 (IO19)
unnamed: RA01.14 (MOSI), SDCARD.3, U$2.D23 (IO23)
unnamed: MQ2.4, RA01.3 (3.3V), U$2.3V3
unnamed: LCD1.1 (VSS), LCD1.3 (VO), LCD1.5 (R/W), MQ2.3, RA01.1 (GND), RA01.2 (GND), RA01.9 (GND), RA01.16 (GND), SDCARD.6, U$2.GND@1 (GND), U$2.GND@2 (GND)
unnamed: LCD1.14 (DB7), U$2.D12 (IO12)
unnamed: LCD1.13 (DB6), U$2.D14 (IO14)
unnamed: LCD1.12 (DB5), U$2.D27 (IO27)
unnamed: LCD1.11 (DB4), U$2.D26 (IO26)
unnamed: LCD1.2 (VDD), SDCARD.5, U$2.VIN
unnamed: LCD1.6 (E), U$2.D33 (IO33)
unnamed: LCD1.4 (RS), U$2.D32 (IO32)
unnamed: MQ2.1, U$2.D2 (IO2)
unnamed: SDCARD.1, U$2.D25 (IO25)

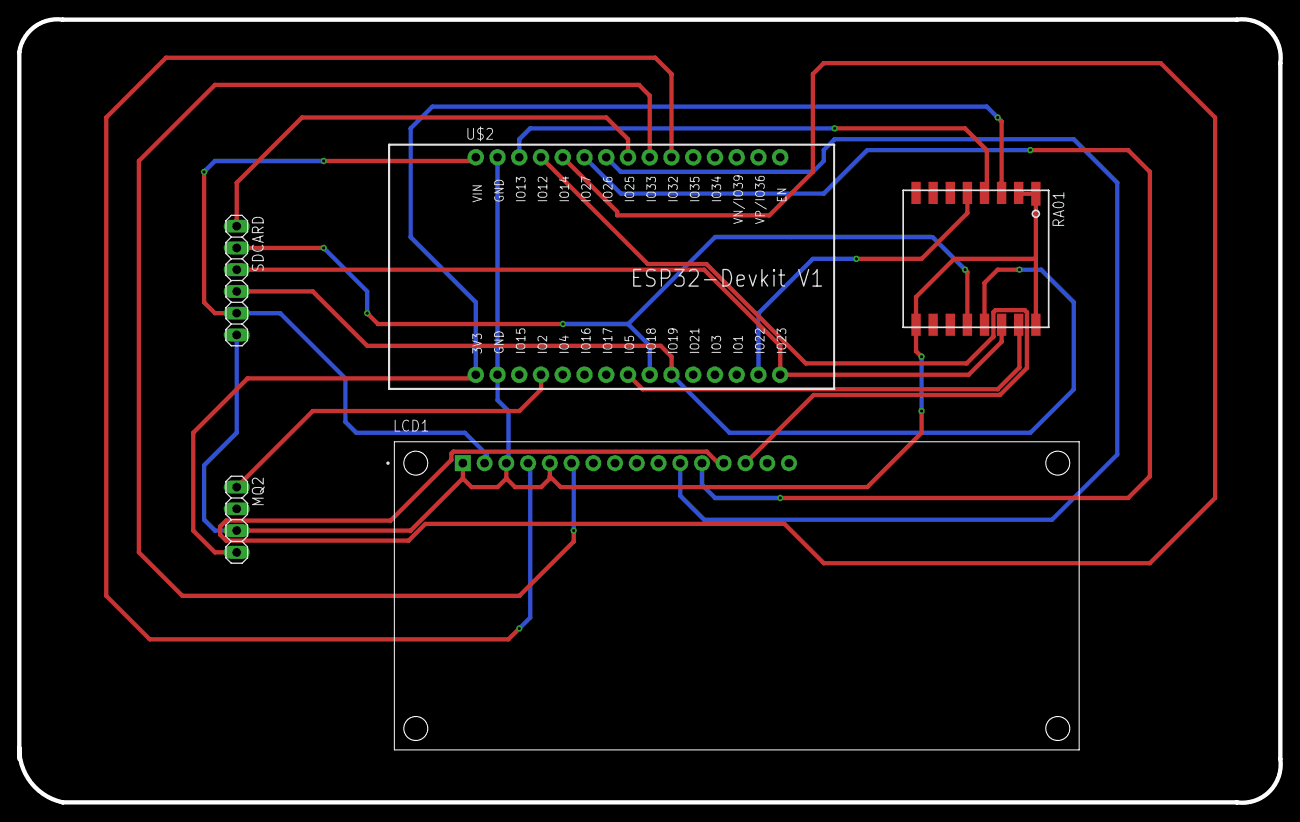
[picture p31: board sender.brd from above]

Board: 2 copper layers, 147.4 x 91.5 mm, 5 parts (0 on the bottom side), 17 nets.

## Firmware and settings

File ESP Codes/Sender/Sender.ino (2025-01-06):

#include <SPI.h>
#include <LoRa.h>
#include <SD.h>
#include <MQ2.h>
#include <LiquidCrystal.h>

// Define LoRa and SD card pin connections
#define SCK     18    // GPIO5 - SCK
#define MISO    19   // GPIO19 - MISO
#define MOSI    23   // GPIO27 - MOSI
#define LORA_SS  5   // Chip select for LoRa
#define SD_SS    4   // Chip select for SD card (choose a different pin for SD card)
#define LORA_RST 14  // RESET for LoRa
#define LORA_DIO0 2   // DIO0 for LoRa

// LCD Display

// D4 -> GPIO 32
// D5 -> GPIO 33
// D6 -> GPIO 26
// D7 -> GPIO 27
// VCC -> 3.3V
// GND -> GND
// Initialize the library with the interface pins
const int rs = 22, en = 21, d4 = 32, d5 = 33, d6 = 26, d7 = 27;
LiquidCrystal lcd(rs, en, d4, d5, d6, d7);

int packet_count = 0;
int pin = 25;
float lpg, co, smoke;

int updateinterval = 5000;
unsigned long lasttime = 0;
int casel = 0;
bool normal = true;

MQ2 mq2(pin);

// LoRa frequency
#define LORA_BAND 433E6

File myFile;

void setup() {
  Serial.begin(115200);
  while (!Serial);

  // Initialize SPI bus for both LoRa and SD card
  SPI.begin(SCK, MISO, MOSI);

  pinMode(SD_SS, OUTPUT);
  pinMode(LORA_SS, OUTPUT);

  // Initialize SD card
  digitalWrite(SD_SS, LOW);
  digitalWrite(LORA_SS, HIGH);
  Serial.println("Initializing SD card...");
  while (!SD.begin(SD_SS, SPI)) {
    Serial.println("SD card initialization failed!");
  }
  Serial.println("SD card initialized.");
  
  uint8_t cardType = SD.cardType();
  if (cardType == CARD_NONE) {
    Serial.println("No SD card attached");
    return;
  }
  uint64_t cardSize = SD.cardSize() / (1024 * 1024);
  Serial.printf("SD Card Size: %lluMB\n", cardSize);

  WriteToSD("LPG,CO,Smoke\n");

  digitalWrite(SD_SS, HIGH);  // Disable SD card
  delay(1000);
  // Initialize LoRa
  digitalWrite(LORA_SS, LOW);  // Disable SD card
  LoRa.setPins(LORA_SS, LORA_RST, LORA_DIO0);
  if (!LoRa.begin(LORA_BAND)) {
    Serial.println("LoRa initialization failed!");
    while (1);
  }
  digitalWrite(LORA_SS, HIGH);  // Disable LoRa
  Serial.println("LoRa initialized.");

  delay(1000);
  // Initialize Sensor
  Serial.println("Calibration Started!");
  mq2.begin();
  delay(1000);
  Serial.println("Calibration done!");

  lcd.begin(16, 2);
  delay(1000);
  lcd.clear();
}

void loop() {
  // Read sensor data
  lpg = mq2.readLPG();
  co = mq2.readCO();
  smoke = mq2.readSmoke();
  if (lpg > 1000 || co > 200 || smoke > 400 || isnan(lpg) || isnan(co) || isnan(smoke)) {
    normal = false;
  } else{
    normal = true;
  }

  // Send data over LoRa
  sendLoRaMessage();

  // Save data to SD card
  saveToSD();

  if(millis() - lasttime > updateinterval){
    LCDdisplay();
    lasttime = millis();
  }

  delay(2000);  // Wait before next iteration
}

void sendLoRaMessage() {
  // Disable SD card, enable LoRa
  digitalWrite(SD_SS, HIGH);
  digitalWrite(LORA_SS, LOW);

  // Send LoRa packet
  LoRa.beginPacket();
  LoRa.print(lpg);
  LoRa.print(" ");
  LoRa.print(co);
  LoRa.print(" ");
  LoRa.print(smoke);
  LoRa.print(" ");
  LoRa.print(++packet_count);

  LoRa.endPacket();

  // Disable LoRa after sending
  digitalWrite(LORA_SS, HIGH);
}

void saveToSD() {
  // Disable LoRa, enable SD card
  digitalWrite(LORA_SS, HIGH);
  digitalWrite(SD_SS, LOW);

  // Save data to SD card
  String message = String(lpg) + "," + String(co) + "," + String(smoke) + "\n";
  Serial.print(message);
  Serial.print(packet_count);
  Serial.println("-----------------------------------------");
  WriteToSD(message.c_str()); 

  // Disable SD card after writing
  digitalWrite(SD_SS, HIGH);
}

void WriteToSD(const char *message) {
  myFile = SD.open("/data.csv", FILE_APPEND);
  if (myFile) {
    myFile.print(message);
    myFile.close();
  } else {
    Serial.println("Error opening file on SD card.");
  }
}

void LCDdisplay(){
  lcd.clear();
  switch(casel){
    case 0:
      lcd.setCursor(0, 0);
      lcd.print("CO : ");
      lcd.print(co);
      lcd.setCursor(0, 1);
      if(normal){
        lcd.print("Safe Level");
      } else{
        lcd.print("Danger! Danger!");
      }
      break;

    case 1:
      lcd.setCursor(0, 0);
      lcd.print("LPG : ");
      lcd.print(lpg);
      lcd.setCursor(0, 1);
      if(normal){
        lcd.print("Safe Level");
      } else{
        lcd.print("Danger! Danger!");
      }
      break;

    case 2:
      lcd.setCursor(0, 0);
      lcd.print("Smoke : ");
      lcd.print(smoke);
      lcd.setCursor(0, 1);
      if(normal){
        lcd.print("Safe Level");
      } else{
        lcd.print("Danger! Danger!");
      }
      break;
  }
  casel+=1;
  casel%=3;
}

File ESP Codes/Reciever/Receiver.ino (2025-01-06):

#include <WiFi.h>
#include <WiFiClient.h>
#include <WiFiServer.h>
#include <WiFiUdp.h>
#include <Server.h>
#include <PubSubClient.h>
#include <ThingSpeak.h>
#include <Wire.h>
#include <MQ2.h>
#include <SPI.h>
#include <LoRa.h>

// Define the LoRa module pin connections
#define LORA_SCK     18    // GPIO5 - SCK
#define LORA_MISO    19   // GPIO19 - MISO
#define LORA_MOSI    23   // GPIO27 - MOSI
#define LORA_SS      5   // GPIO18 - NSS
#define LORA_RST     14  // GPIO14 - RESET
#define LORA_DIO0    2   // GPIO26 - DIO0

// Define the frequency for LoRa communication (433 MHz, 868 MHz, or 915 MHz)
#define LORA_BAND    433E6  // 433 MHz (Adjust according to your region)

const char* ssid = "Hiten17";
const char* pass = "qwerty12";

// Ensure that the credentials here allow you to publish and subscribe to the ThingSpeak channel.
const long channelID = 2687973;  // Replace 123456 with your actual ThingSpeak channel number 
const char mqttUserName[] = "BQMWHSM1Ny4lCzkRMDsQLRQ";
const char clientID[] = "BQMWHSM1Ny4lCzkRMDsQLRQ";
const char mqttPass[] = "zFipNYCiHte2pLUVoKiKgm6o";

#define mqttPort 1883
WiFiClient client;
const char* server = "mqtt3.thingspeak.com";
int status = WL_IDLE_STATUS;
long lastPublishMillis = 0;
int connectionDelay = 1;
int updateInterval = 5;
int rssi;
int ssr;

PubSubClient mqttClient(client);

float lpg, co, smoke, packetNumber;
String incomingMessage;

void setup() {
  // Initialize the Serial Monitor for debugging
  Serial.begin(115200);
  while (!Serial);

  // Setup LoRa pins
  LoRa.setPins(LORA_SS, LORA_RST, LORA_DIO0);

  // Start LoRa module with the defined frequency
  if (!LoRa.begin(LORA_BAND)) {
    Serial.println("LoRa initialization failed!");
    while (1);
  }
  Serial.println("LoRa initialized successfully!");
  connectWifi();
  mqttClient.setServer(server, mqttPort);

  delay(3000);
}

void loop() {
  // Check if there's an incoming packet
  // how to recieve multiple packets ?

  if (WiFi.status() != WL_CONNECTED) {
    connectWifi();
  }
  if (!mqttClient.connected()) {
    mqttConnect();
    mqttSubscribe(channelID);
  }
  mqttClient.loop();
  delay(100);


  int packetSize = LoRa.parsePacket();
  if (packetSize) {
    // Read packet and print its content
    Serial.print("Received packet: ");

    // Read the incoming message
    while (LoRa.available()) {
      incomingMessage = LoRa.readString();
      // Serial.print(incomingMessage);
    }
    // Serial.println();
    Serial.println(incomingMessage);
    Serial.println("-----------------------------");
    rssi = LoRa.packetRssi();  // Get RSSI value
    Serial.print("Signal strength (RSSI): ");
    Serial.println(rssi);          // Print RSSI value
    ssr = LoRa.packetSnr();    // Get SNR value // Signal to noise ratio 
    Serial.print("Signal to noise ratio (SNR): ");
    Serial.println(ssr);           // Print SNR value
    Serial.println("-----------------------------");
  }

   if (incomingMessage.length() > 0) {
      // Assume the incoming message is in the format: "lpg,co,smoke"
      int commaIndex1 = incomingMessage.indexOf(' ');
      int commaIndex2 = incomingMessage.indexOf(' ', commaIndex1 + 1);
      int commaIndex3 = incomingMessage.indexOf(' ',commaIndex2 + 1);
  
    if (commaIndex1 != -1 && commaIndex2 != -1 && commaIndex3 != -1) {
        // Extract LPG, CO, and smoke values from the message
        String lpgString = incomingMessage.substring(0, commaIndex1);
        String coString = incomingMessage.substring(commaIndex1 + 1, commaIndex2);
        String smokeString = incomingMessage.substring(commaIndex2 + 1, commaIndex3);
        String PacketString = incomingMessage.substring(commaIndex3 + 1);

        // Convert the strings to float values
        lpg = lpgString.toFloat();
        co = coString.toFloat();
        smoke = smokeString.toFloat();
        packetNumber = PacketString.toFloat();

        // Print the separated values for debugging
        // Serial.print("LPG: ");
        // Serial.println(lpg);
        // Serial.print("CO: ");
        // Serial.println(co);
        // Serial.print("Smoke: ");
        // Serial.println(smoke);
        if (abs(long(millis()) - lastPublishMillis) > updateInterval * 1000) {
          String topicString = "channels/" + String(channelID) + "/publish";

          String message = "&field1=" + String(co);
          message += "&field2=" + String(smoke);
          message += "&field3=" + String(lpg);
          message += "&field4=" + String(rssi);
          message += "&field5=" + String(ssr);
          message += "&field6=" + String(packetNumber);
          mqttClient.publish(topicString.c_str(), message.c_str());
          lastPublishMillis = millis();
        }
    } else {
      // Serial.println("Error: Invalid packet format.");
    }
  }


}
void mqttConnect() {
  while (!mqttClient.connected()) {
    if (mqttClient.connect(clientID, mqttUserName, mqttPass)) {
      Serial.println("MQTT connected.");
    } else {
      Serial.print("MQTT connection failed, rc=");
      Serial.println(mqttClient.state());
      // delay(5000);
    }
  }
}
void connectWifi() {
  Serial.println("Connecting to Wi-Fi...");
  while (WiFi.status() != WL_CONNECTED) {
    WiFi.begin(ssid, pass);
    delay(1000);
    Serial.println(".");
  }
  Serial.println("Connected to Wi-Fi");
}
void mqttSubscribe(long subChannelID) {
  String myTopic = "channels/" + String(subChannelID) + "/subscribe";
  mqttClient.subscribe(myTopic.c_str());
}
